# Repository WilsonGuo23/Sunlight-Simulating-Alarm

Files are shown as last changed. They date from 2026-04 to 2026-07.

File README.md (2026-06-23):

# Sunlight-Simulating-Alarm

A microcontroller-based alarm clock that simulates a natural sunrise by gradually increasing light intensity as the configured wake-up time approaches. The system uses a TRIAC-based AC dimmer to control a dimmable daylight bulb, helping create a more gradual and comfortable waking experience.

## Features
* Configurable alarm time
* Sunrise simulation with gradual brightness increase
* Real-time clock synchronization
* TM1637 7-segment display for time and alarm settings
* Push-button user interface
* TRIAC-based AC light dimming control
* Custom 3D-printed enclosure

# Schematic
Sunlight Alarm Schematic

## Hardware
| Quantity | Component |
| --- | --- |
| 1 | Raspberry Pi Pico |
| 1 | TRIAC Dimmer Module |
| 1 | TM1637 Display Module |
| 1 | Dimmable Daylight Bulb |
| 1 | Power Strip with USB Port |
| 1 | 1-In / 2-Out Terminal Block |
| 5 | 24 mm Push Buttons |
| 5 | 110 mm Quick-Disconnect Crimps |
| 2 ft | 20 AWG Copper Wire |
| 0.5 ft | 16 AWG Copper Wire |

## Fasteners
| Quantity | Component |
| --- | --- |
| 4 | M3 × 25 mm Screws  |
| 10 | M3 × 20 mm Screws  |
| 4 | M3 × 15 mm Screws  |
| 4 | M3 × 10 mm Screws  |
| 4 | M2.5 × 5 mm Screws |
| 4 | M2 × 10 mm Screws  |
| 10 | M3 Nuts |
| 4 | M2.5 Nuts |
| 4 | M2 Nuts |
| 4 | M3 Connector Bolts |

## 3D Printed Parts
| Quantity | Part |
| --- | --- |
| 4 | Pico Standoffs |
| 4 | TRIAC Standoffs |
| 1 | Bottom Panel |
| 1 | Light Bulb Bracket |
| 1 | Mounting Bracket |
| 1 | Lower Middle Wall  |
| 1 | Upper Middle Wall  |
| 1 | Top Panel |

# Assembly
Engineering Drawings can be found in the "Mechanical Schematics" folder, you can also use the assembly in the SLDPRT Files as a reference intended assembly
Assembly Instructions

Engineering drawings can be found in the Mechanical Schematics directory. The SolidWorks assembly files (SLDPRT and assembly files) may also be used as references during assembly.

## 1. Install Electronics
Mount the Raspberry Pi Pico and TRIAC dimmer to the mounting bracket using:
M2 × 10 mm screws and M2 nuts (Pico)
M3 × 10 mm screws and M3 nuts (TRIAC dimmer)
Appropriate standoffs
Ensure the AC terminal connections on the TRIAC dimmer face outward from the mounting bracket for easy wiring access.
Secure the mounting bracket to the bottom panel using M3 × 15 mm screws and M3 nuts.
## 2. Install Power Strip
Insert the power strip into the rectangular opening in the bottom panel.
Orient the power strip so:
The cable exit aligns with the enclosure notch.
The USB ports face upward.
## 3. Complete Wiring
Wire all components according to the electrical schematic.
Leave approximately 90 mm of wire for connections to:
Push buttons
TM1637 display

This provides sufficient length to reach the upper section of the enclosure.

## 4. Assemble Lower Section
Insert an M3 connector bolt into each corner recess of the bottom panel.
Secure each connector bolt using an M3 × 25 mm screw.
Attach the lower middle wall to the bottom panel using M3 × 20 mm screws.
Route all wires through the wire passage before tightening the fasteners.
## 5. Assemble Upper Section
Install the push buttons into the upper middle wall.
Install the light bulb socket into the top panel.
Mount the TM1637 display using M2.5 screws and M2.5 nuts.
Secure the light bulb socket using:
Light bulb bracket
M3 × 20 mm screws
M3 nuts
Attach the top panel to the upper middle wall using M3 × 20 mm screws and M3 nuts.
## 6. Final Wiring and Assembly
Connect the remaining wiring to all buttons and peripherals.
Verify all connections against the electrical schematic.
Perform a functional test before closing the enclosure.
Secure the lower and upper middle walls together using two zip ties.
## 7. Final Installation
Install the light bulb.
Connect power to the unit.
Verify proper operation of the display, buttons, and sunrise simulation.

Your Sunlight Simulating Alarm is now ready for use.

# Safety Notice
⚠️ Warning: This project contains mains-voltage AC wiring. Improper assembly can result in electric shock, fire, or equipment damage. Always disconnect power before servicing the device and verify all wiring connections before operation. If you are unfamiliar with AC electrical systems, seek assistance from a qualified individual.

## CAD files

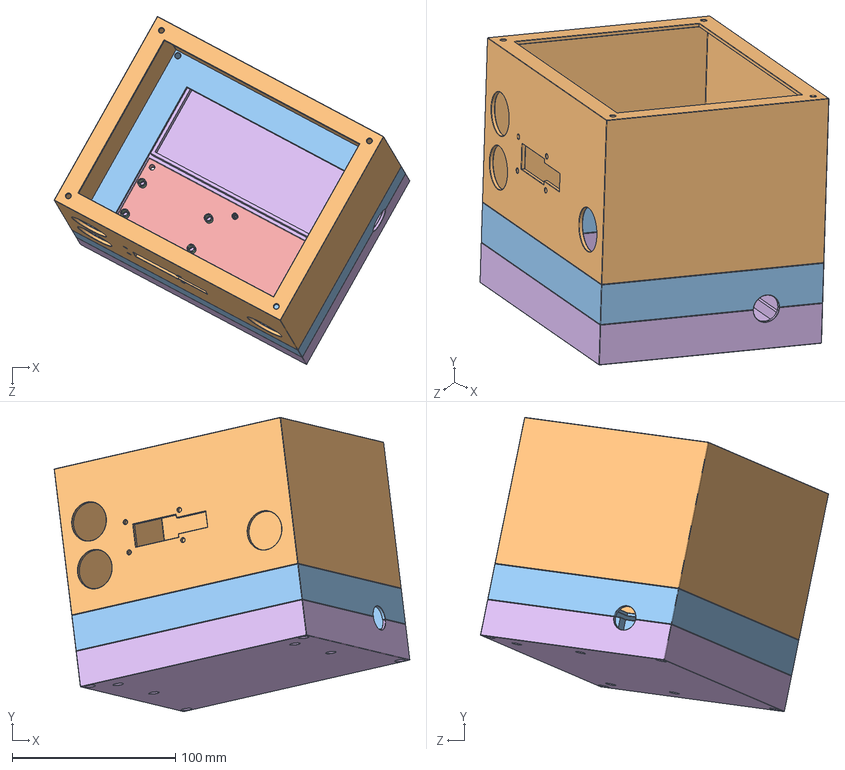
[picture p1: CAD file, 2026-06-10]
SLDprt Files/Alarm Assembly.SLDASM
217.6 x 180.0 x 212.9 mm
Bottom Panel
Mounting Bracket
Triac Standoff x 4
Lower Middle Wall
Upper Middle Wall
Pico Standoff x 4

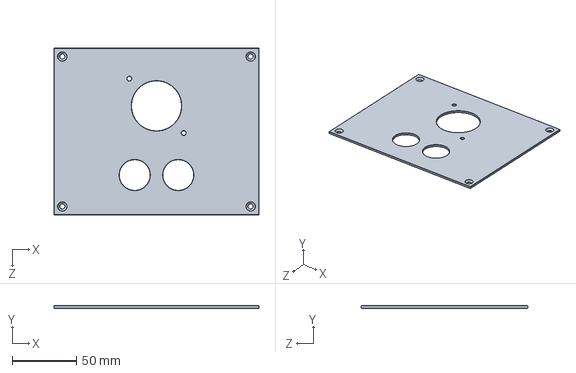
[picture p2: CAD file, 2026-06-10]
SLDprt Files/Top Panel.SLDPRT
160.0 x 2.00 x 130.0 mm

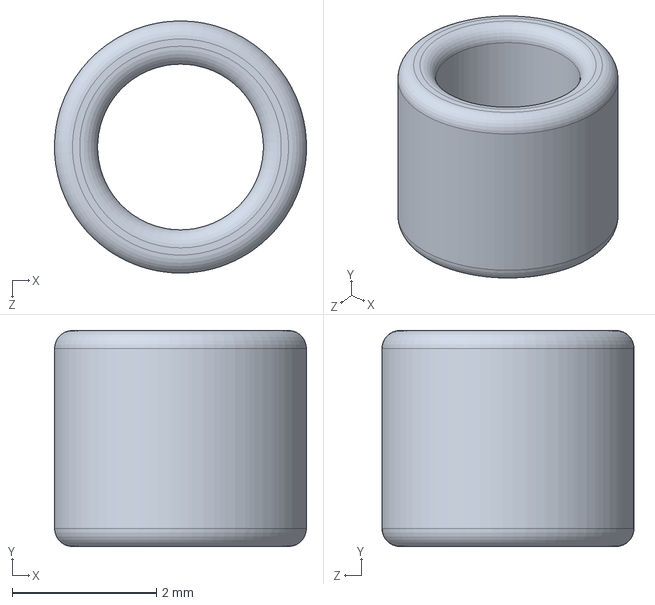
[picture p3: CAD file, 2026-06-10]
SLDprt Files/Pico Standoff.SLDPRT
3.50 x 3.00 x 3.50 mm

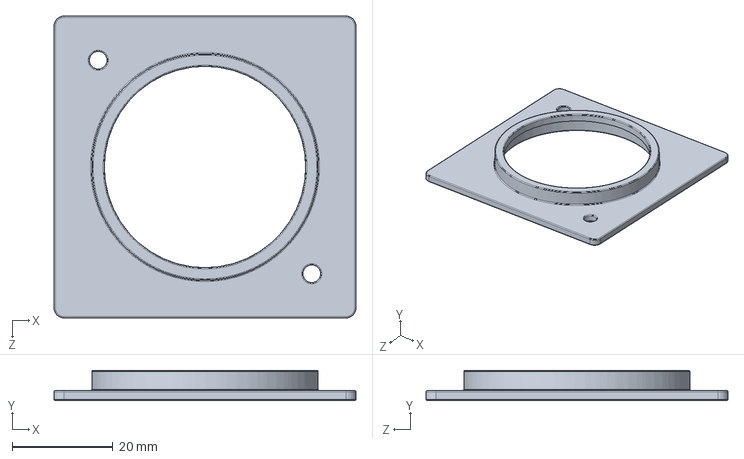
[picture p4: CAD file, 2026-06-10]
SLDprt Files/Lightbulb Bracket.SLDPRT
60.0 x 6.00 x 60.0 mm

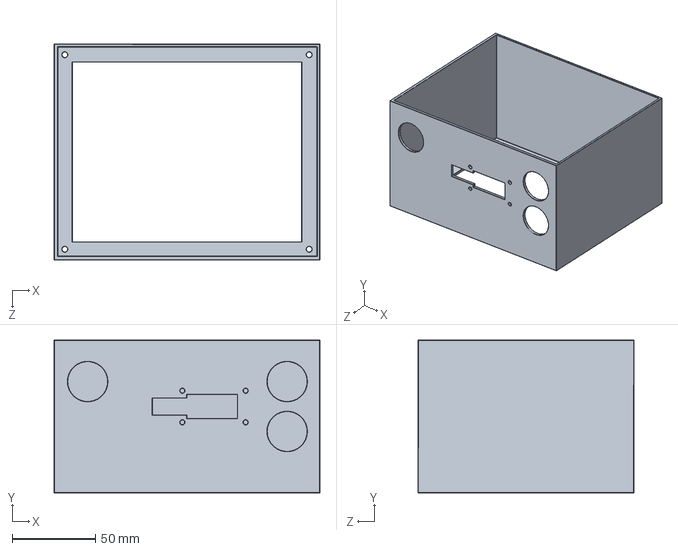
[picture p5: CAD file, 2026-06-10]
SLDprt Files/Upper Middle Wall.SLDPRT
160.0 x 92.0 x 130.0 mm

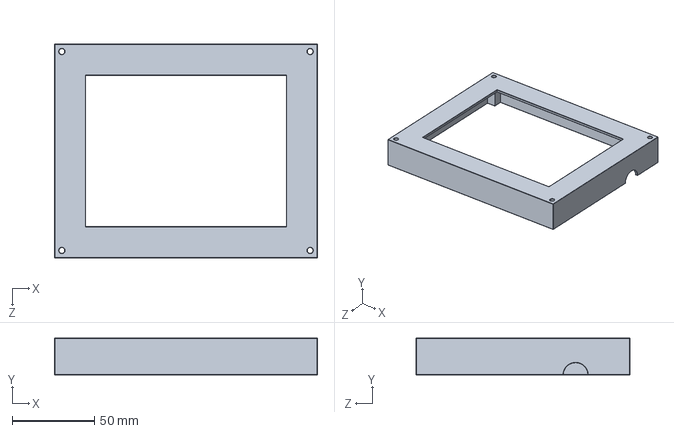
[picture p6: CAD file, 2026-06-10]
SLDprt Files/Lower Middle Wall.SLDPRT
160.0 x 22.5 x 130.0 mm

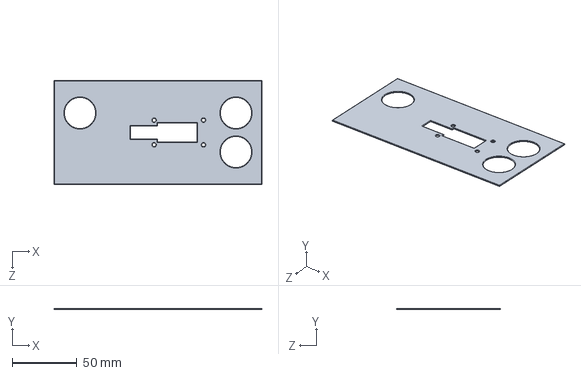
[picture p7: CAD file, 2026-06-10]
SLDprt Files/Test_Display_Panel.SLDPRT
160.0 x 1.00 x 80.0 mm

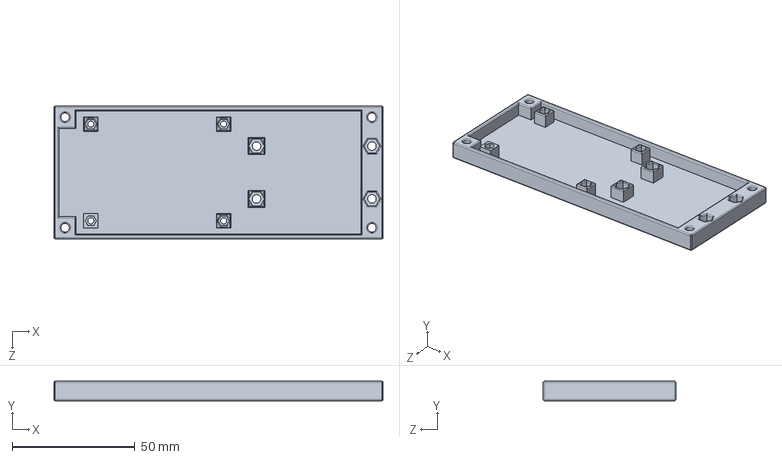
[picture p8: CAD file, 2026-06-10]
SLDprt Files/Mounting Bracket.SLDPRT
134.0 x 8.00 x 54.0 mm

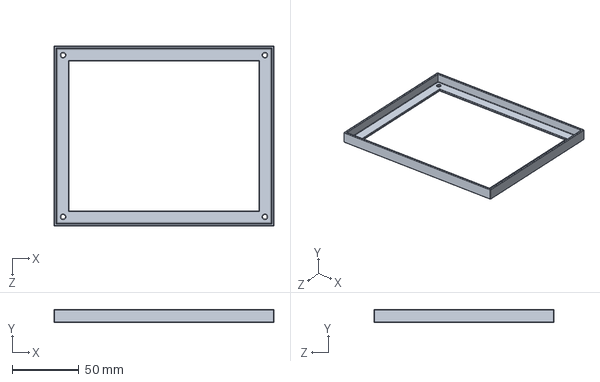
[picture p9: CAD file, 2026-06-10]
SLDprt Files/Middle Wall Connector.SLDPRT
164.6 x 10.0 x 134.6 mm

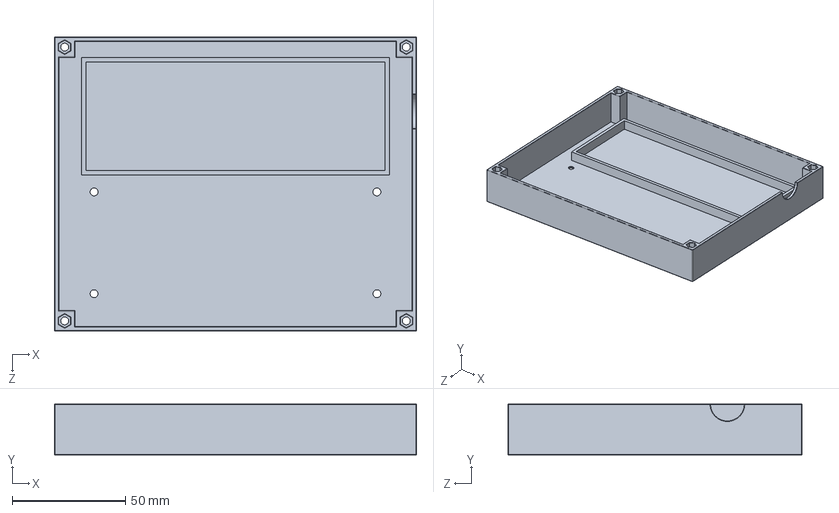
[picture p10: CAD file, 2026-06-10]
SLDprt Files/Bottom Panel.SLDPRT
160.0 x 22.5 x 130.0 mm

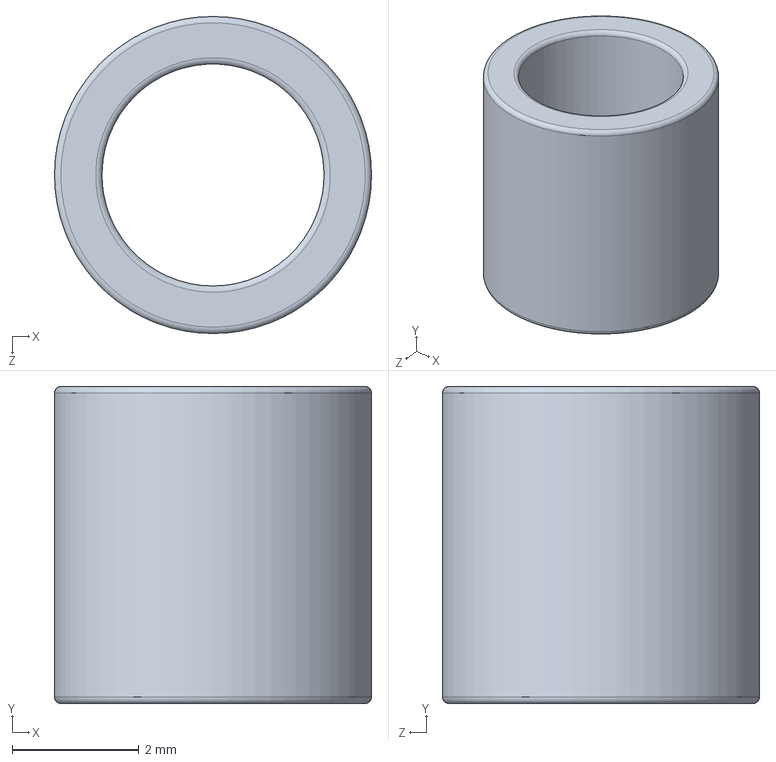
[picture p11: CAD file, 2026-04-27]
SLDprt Files/Triac Standoff.SLDPRT
5.00 x 5.00 x 5.00 mm

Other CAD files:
Mechanical Schematics/Bottom Panel.SLDDRW
STL Files/Bottom Panel.STL
STL Files/Lightbulb Bracket.STL
STL Files/Lower Middle Wall.STL
STL Files/Middle Wall Connector.STL
STL Files/Mounting Bracket.STL
STL Files/Pico Standoff.STL
STL Files/Test_Display_Panel.STL
STL Files/Top Panel.STL
STL Files/Triac Standoff.STL
STL Files/Upper Middle Wall.STL

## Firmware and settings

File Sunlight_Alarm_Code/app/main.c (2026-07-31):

#include <stdio.h>
#include "pico/stdlib.h"

#include "FreeRTOS.h"
#include "task.h"
#include "pins.h"

#include "system_init.h"
#include "services/time_service.h"
#include "services/display_service.h"
#include "services/input_service.h"
#include "services/alarm_service.h"
#include "services/ui_service.h"

//TODO: make alarm task able to rest until needed, instead of checking every 10 seconds. This will reduce CPU usage and allow for more accurate alarm triggering.

// Updates the display every 1/2 second depending on the mode (clock, set time, set alarm, display off)
void display_task(void *p)
{
    bool flicker = false;
    while (1) {
        uint8_t hour, minute;
        ui_mode_t mode = ui_service_get_mode();
        bool hour_mode = ui_service_get_hour_mode();
        if(flicker) {
            flicker = false;
        }
        else {
            flicker = true;
        }
        switch (mode)
        {
            case UI_MODE_CLOCK:
                time_service_get(&hour, &minute);
                display_service_show_time(hour, minute, hour_mode, false);
                break;

            case UI_MODE_SET_TIME:
                time_service_get(&hour, &minute);
                display_service_show_time(hour, minute, hour_mode, flicker);
                break;

            case UI_MODE_SET_ALARM:
                alarm_service_get_alarm(&hour, &minute);
                display_service_show_time(hour, minute, hour_mode, flicker);
                break;

            case UI_MODE_DISPLAY_OFF:
                display_service_clear();
                //vTaskSuspend(NULL);
                break;
        }
        vTaskDelay(pdMS_TO_TICKS(500));
    }
    
}

// Checks if the current time is equal to the alarm time, and starts sunrise if so
//checks if alarm should be triggered every 10 seconds
void alarm_task(void *p)
{
    while (1) {
        vTaskDelay(pdMS_TO_TICKS(10000));
        alarm_service_update();
    }
}

//update the internal clock every minute
void time_task(void *pvParameters)
{
    (void)pvParameters;

    while (1)
    {
        time_service_update();
        vTaskDelay(pdMS_TO_TICKS(60000));
    }
}

//update sunrise brightness every second
void sunrise_task(void *pvParameters)
{
    (void)pvParameters;

    while (1)
    {
        sunrise_service_update();
        vTaskDelay(pdMS_TO_TICKS(1000));
    }
}

//receives button presses and handles them appropriately
void handle_button_press(button_t button)
{
    switch (button)
    {
        case BUTTON_INC: //increments clock/timer
            if (ui_service_get_mode() == UI_MODE_SET_TIME)
            {
                time_service_increment(ui_service_get_hour_mode());
            }
            else if (ui_service_get_mode() == UI_MODE_SET_ALARM)
            {
                alarm_service_increment(ui_service_get_hour_mode());
            }
            break;

        case BUTTON_DEC: //decrements clock/timer
            if (ui_service_get_mode() == UI_MODE_SET_TIME)
            {
                time_service_decrement(ui_service_get_hour_mode());
            }
            else if (ui_service_get_mode() == UI_MODE_SET_ALARM)
            {
                alarm_service_decrement(ui_service_get_hour_mode());
            }
            break;

        case BUTTON_MODE: //changes display mode
            ui_service_next_mode();
            break;

        case BUTTON_SNOOZE: //turns off lightbulb alarm
            sunrise_service_stop();
            break;

        case BUTTON_HOUR_MIN: //toggles between hour and mins for incrementing and decrementing functions
            ui_service_toggle_hour_mode();
            break;

        default:
            break;
    }

}

//checks queue for button presses, then pass them to handle_button_press
void button_processing_task(void *pvParameters)
{
    input_event_t evt;

    while (1)
    {
        if (xQueueReceive(input_service_get_queue(),
                          &evt,
                          portMAX_DELAY) == pdPASS && evt.type == INPUT_EVENT_PRESS)
        {
            handle_button_press(evt.button);
        }
    }
}



int main(void)
{
    //initialize drivers and services
    system_init();

    time_service_init();
    display_service_init();
    input_service_init();
    alarm_service_init();
    ui_service_init();

    //create tasks that will run through the scheduler
    xTaskCreate(time_task, "time_update", 256, NULL, 1, NULL); //updates clock every minute
    xTaskCreate(input_task, "input", 256, NULL, 3, NULL); //reads buttons and generates events in queue
    xTaskCreate(alarm_task, "alarm", 256, NULL, 2, NULL); //checks if alarm should be triggered every 10 seconds
    xTaskCreate(display_task, "display", 512, NULL, 1, NULL); //updates display every 1/2 second depending on mode (clock, set time, set alarm, display off)
    xTaskCreate(button_processing_task, "button_check", 512, NULL, 2, NULL); //processes button events and prints to console which button is being pressed, held, or released, and for how long
    xTaskCreate(sunrise_task, "sunrise", 256, NULL, 2, NULL); //updates sunrise brightness every second

    //run tasks
    vTaskStartScheduler();
}

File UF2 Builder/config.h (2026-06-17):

#ifndef CONFIG_H
#define CONFIG_H

#define GPIO_WATCH_PIN      16
#define GPIO_INCREMENT_PIN  18
#define GPIO_DECREMENT_PIN  19
#define GPIO_MOVE_PIN       17
#define SNOOZE_PIN          20

#define TRIAC_PIN           0
#define ZERO_CROSS_PIN      1

#define DIO                 2
#define CLK                 3

#define BIT(n)  (1u<<(n))
#define BIT_MASK BIT(0)|BIT(1)|BIT(2)|BIT(3)|BIT(12)|BIT(16)|BIT(17)|BIT(18)|BIT(19)|BIT(20)
#endif

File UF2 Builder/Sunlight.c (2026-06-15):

#include <stdio.h>
#include "pico/stdlib.h"
#include <time.h>
#include <string.h>

#include "config.h"
#include "display.h"
#include "time_manager.h"
#include "buttons.h"
#include "dimmer.h"


#include "alarm_manager.h"
// ========================================
// GLOBAL VARIABLES
// ========================================

uint64_t last_clock_update = 0;
uint64_t last_display_update = 0;

struct tm* clock_time;


// ========================================
// LIGHT CONTROL
// ========================================

// Used only by display update logic now
static bool flicker = false;



// Light control moved to dimmer module

// ========================================
// ALARM FUNCTIONS moved to alarm_manager.c

// ========================================
// INITIALIZATION
// ========================================

static void master_init()
{
    stdio_init_all();

    time_manager_init();
    clock_time = time_manager_get_time();
    gpio_init_mask(BIT_MASK);
    // Initialize buttons (IRQ setup, input direction, pull-ups)
    buttons_init();

    // Zero-cross and triac pins
    gpio_set_irq_enabled(ZERO_CROSS_PIN, GPIO_IRQ_EDGE_FALL, true);

    gpio_set_dir(ZERO_CROSS_PIN, GPIO_IN);
    gpio_set_dir(TRIAC_PIN, GPIO_OUT);

    alarm_manager_init(clock_time);
}

// ========================================
// MAIN
// ========================================

int main()
{
    master_init();

    display_init();

    while(true)
    {
        uint64_t now = time_us_64();

        if(change_mode_flag)
        {
            change_mode();
            change_mode_flag = false;
        }

        if(increment_flag)
        {
            increment_column();
            increment_flag = false;
        }

        if(decrement_flag)
        {
            decrement_column();
            decrement_flag = false;
        }

        if(move_flag)
        {
            move_column();
            move_flag = false;
        }

        if(snooze_flag)
        {
            alarm_on = false;
            snooze_flag = false;

            dimmer_reset_delay();
            gpio_set_irq_enabled(
                ZERO_CROSS_PIN,
                GPIO_IRQ_EDGE_FALL,
                false);
            gpio_put(TRIAC_PIN, 0);
        }

        if(now - last_display_update >= 500000)
        {
            last_display_update = now;

            bool blink_hours = false;
            bool blink_minutes = false;

            if(current_mode != RESTING)
            {
                flicker = !flicker;

                if(minutes_selected)
                {
                    blink_minutes = !flicker;
                }
                else
                {
                    blink_hours = !flicker;
                }
            }

            if(current_mode == MODE_SET_ALARM_TIME)
            {
                display_show_time(
                    alarm_time_hours,
                    alarm_time_minutes,
                    blink_hours,
                    blink_minutes);
            }
            else
            {
                display_show_time(
                    clock_time->tm_hour,
                    clock_time->tm_min,
                    blink_hours,
                    blink_minutes);
            }
        }

        if(now - last_clock_update >= 1000000)
        {
            last_clock_update = now;

            clock_increment();

            alarm_check();
        }

        dimmer_update(now, alarm_on);
    }
}

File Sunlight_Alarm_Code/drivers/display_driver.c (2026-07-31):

#include <stdint.h>
#include <stdbool.h>

#include "stdio.h"
#include "FreeRTOS.h"
#include "queue.h"
#include "hardware/gpio.h"
#include "hardware/timer.h"
#include "pico/stdlib.h"

#include "display_driver.h"

//TODO: make this non blocking

/* =========================
 * TM1637 GPIO configuration
 * ========================= */
static uint8_t _clk_pin;
static uint8_t _dio_pin;
static bool queue_processing_active = false;

typedef struct
{
    uint8_t pin;
    bool level;
    uint64_t delay;
} pin_change_t;

static QueueHandle_t pin_state_queue_;

/* =========================
 * 7-segment encoding table
 * Each byte maps a digit (0–9)
 * to TM1637 segment bit pattern
 * ========================= */
static const uint8_t digit_map[10] = {
    0x3F, // 0
    0x06, // 1
    0x5B, // 2
    0x4F, // 3
    0x66, // 4
    0x6D, // 5
    0x7D, // 6
    0x07, // 7
    0x7F, // 8
    0x6F  // 9
};




static void queue_pin_state(uint8_t pin, bool level, uint64_t delay)
{
    pin_change_t change = {.pin = pin, .level = level, .delay = delay};

    if (pin_state_queue_ != NULL)
    {
        xQueueSendToBack(pin_state_queue_, &change, 0);
    }
}

static int64_t set_pin(alarm_id_t id, void *user_data){

    queue_processing_active = true;
    pin_change_t next_change;

    if (xQueueReceiveFromISR(pin_state_queue_, &next_change, NULL) == pdPASS)
    {
        gpio_put(next_change.pin, next_change.level);
        printf("pin: %d, level: %d, delay: %llu\n", next_change.pin, next_change.level, next_change.delay);
    }
    else
    {
        queue_processing_active = false;
        return 0; // No more changes to process
    }

    if (uxQueueMessagesWaitingFromISR(pin_state_queue_) > 0)
    {
        add_alarm_in_us(next_change.delay, set_pin, NULL, true);
    }

    return 0;
}

void process_queue(){
    if (!queue_processing_active){
        add_alarm_in_us(0, set_pin, NULL, false);
    }
    while (queue_processing_active);
}
/* =========================================================
 * Start condition for TM1637 communication
 * CLK high → DIO high → DIO low (data start condition)
 * ========================================================= */
/*static void start_display(void)
{
    queue_pin_state(_clk_pin, 1,0);
    queue_pin_state(_dio_pin, 1,2);
    queue_pin_state(_dio_pin, 0,2);
    process_queue();
}*/
static void start_display(void)
{
    gpio_put(_clk_pin, 1);
    gpio_put(_dio_pin, 1);
    sleep_us(2);
    gpio_put(_dio_pin, 0);
}

/* =========================================================
 * Stop condition for TM1637 communication
 * CLK low → DIO low → CLK high → DIO high
 * ========================================================= */
/*static void stop_display(void)
{
    queue_pin_state(_clk_pin,0,2);
    queue_pin_state(_dio_pin,0,2);
    queue_pin_state(_clk_pin,1,2);
    queue_pin_state(_dio_pin,1,2);
    process_queue();
}*/
static void stop_display(void)
{
    gpio_put(_clk_pin, 0);
    sleep_us(2);
    gpio_put(_dio_pin, 0);
    sleep_us(2);
    gpio_put(_clk_pin, 1);
    sleep_us(2);
    gpio_put(_dio_pin, 1);
}
/* =========================================================
 * Write one byte to TM1637 (LSB first)
 * Clock pulses shift data into display driver
 * ========================================================= */
/*static void write_byte(uint8_t data)
{
    for (int i = 0; i < 8; ++i)
    {
        queue_pin_state(_clk_pin, 0,0);
        queue_pin_state(_dio_pin, data & 0x01,3); // send LSB

        data >>= 1; // shift to next bit

        queue_pin_state(_clk_pin, 1,3);
    }
    process_queue();
}*/
static void write_byte(uint8_t data)
{
    for (int i = 0; i < 8; ++i)
    {
        gpio_put(_clk_pin, 0);
        gpio_put(_dio_pin, data & 0x01); // send LSB
        sleep_us(3);

        data >>= 1; // shift to next bit

        gpio_put(_clk_pin, 1);
        sleep_us(3);
    }
}


/* =========================================================
 * ACK cycle from TM1637
 * Temporarily release DIO and wait for acknowledgment
 * Includes timeout to avoid hanging
 * ========================================================= */
/* static void ack_cycle(void)
{
    uint64_t timeout = time_us_64();
    gpio_put(_clk_pin, 0);

     //Release DIO line for ACK from display 
    gpio_set_dir(_dio_pin, GPIO_IN);

    // Wait for device to pull line low (ACK) 
    while (gpio_get(_dio_pin))
    {
        if (time_us_64() - timeout > 1000)
        {
            break; // timeout safety
        }
    }

    //Restore DIO as output 
    gpio_set_dir(_dio_pin, GPIO_OUT);
    queue_pin_state(_clk_pin, 1, 2);
    queue_pin_state(_clk_pin, 0, 2);
    process_queue();
}*/

static void ack_cycle(void)
{
    uint64_t timeout = time_us_64();

    gpio_put(_clk_pin, 0);

    /* Release DIO line for ACK from display */
    gpio_set_dir(_dio_pin, GPIO_IN);
    sleep_us(5);

    /* Wait for device to pull line low (ACK) */
    while (gpio_get(_dio_pin))
    {
        if (time_us_64() - timeout > 1000)
        {
            break; // timeout safety
        }
    }

    /* Restore DIO as output */
    gpio_set_dir(_dio_pin, GPIO_OUT);

    gpio_put(_clk_pin, 1);
    sleep_us(2);
    gpio_put(_clk_pin, 0);
}

/* =========================================================
 * Send a command byte to TM1637
 * Used for configuration (brightness, mode, etc.)
 * ========================================================= */
static void send_command(uint8_t command)
{
    start_display();
    write_byte(command);
    ack_cycle();
    stop_display();
}

static void big_send_command(uint8_t command)
{
    //start
    queue_pin_state(_clk_pin, 1,0);
    queue_pin_state(_dio_pin, 1,2);
    queue_pin_state(_dio_pin, 0,2);

    // write byte
    for (int i = 0; i < 8; ++i)
    {
        queue_pin_state(_clk_pin, 0,0);
        queue_pin_state(_dio_pin, command & 0x01,3); // send LSB

        command >>= 1; // shift to next bit

        queue_pin_state(_clk_pin, 1,3);
    }
    //ack
    uint64_t timeout = time_us_64();
    queue_pin_state(_clk_pin, 0, 0);
    process_queue();

     //Release DIO line for ACK from display 
    gpio_set_dir(_dio_pin, GPIO_IN);

    // Wait for device to pull line low (ACK) 
    while (gpio_get(_dio_pin))
    {
        if (time_us_64() - timeout > 1000)
        {
            printf("connection timed out\n");
            break; // timeout safety
        }
    }

    //Restore DIO as output 
    gpio_set_dir(_dio_pin, GPIO_OUT);
    queue_pin_state(_clk_pin, 1, 2);
    queue_pin_state(_clk_pin, 0, 2);
    //stop
     queue_pin_state(_clk_pin,0,2);
    queue_pin_state(_dio_pin,0,2);
    queue_pin_state(_clk_pin,1,2);
    queue_pin_state(_dio_pin,1,2);
    process_queue();

}
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

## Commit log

2025-11-12 Interrupt infrastructure complete
    finished creating the GPIO interrupt infrastructure. The project should start to be usable in the next week or two
2025-11-21 Time.h update
    finished most of the functions related to time, will port to something a bit more independent from the usb cable in the future. next step is to have the led start to light up
2026-04-08 Basic Enclosure Design
    enclosure design - side panels
    [Bottom Panel.SLDPRT, Lightbulb Bracket.SLDPRT, Mounting Bracket.SLDPRT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]
2026-04-27 Added Parts
    Created base enclosure and some standoffs to prevent interference
    [Alarm Assembly.SLDASM, Bottom Panel.SLDPRT, Bottom Panel.STL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]
2026-05-12 RTC update
    Implemented RTC logic to set the stage for being able to put it all together
2026-05-13 Button Control for alarms
    Button Controls are functional they have some issue related to debouncing I will handle later. TODO: rework light functions to use fewer interrupts
    [Sunlight.c]
2026-05-15 Cleaning
    Added Snooze button and replace zero cross function, will need to work on zero cross further
    [Sunlight.c]
2026-05-15 Features complete
    finished implementing all relevant features and converting interrupts to set flags instead of directly running code for non time sensitive things
2026-05-20 Update README with BOM and STL files
    Added Bill of Materials and STL files sections to README.
2026-05-20 Enclosure changes and bugfix
    made changes to enclosure draft and fixed a bug where snooze would cause gpio interrupt problems
    [Top Panel.SLDPRT]
2026-05-27 Changes to case design
    reworked case design for a smaller power strip, still needs a top cover but overall much closer to a finished product. also made some code changes to allow the light level to increase
    [Alarm Assembly.SLDASM, Bottom Panel.SLDPRT, Bottom Panel.STL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]
2026-06-10 Final Assembly
    [Alarm Assembly.SLDASM, Bottom Panel.SLDPRT, Bottom Panel.STL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]
2026-06-10 Enhance assembly section with detailed instructions
    Added detailed assembly instructions for the project, including steps for wiring and component installation.
2026-06-15 Modularized Code
    Separated functions by category into separate modules, also seems to have improved performance, no clue why
    [Bottom Panel.SLDDRW]
2026-06-17 RTOS port ground work
    Finished Drivers for RTOS port, also made a tweak to pin set to match schematic better
2026-06-18 Fixed lighting curve
    Made changes to how lighting functions to avoid low spots and flickering
    [triac_driver.c]
2026-07-31 allow display driver to have pins set via init instead of directly using pins.h
